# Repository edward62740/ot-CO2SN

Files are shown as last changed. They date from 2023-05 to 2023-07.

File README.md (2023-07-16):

# ot-CO2SN
 
## Overview

This is a photoacoustic NDIR CO<sub>2</sub> sensor node, utilizing energy harvesting from PV cells to allow for batteryless operation.[^1]<br>
The sensor communicates with the backend/database through 6LoWPAN on a Thread network.

Refer to the functional block diagram below for an overview of the circuit design. <br><br>
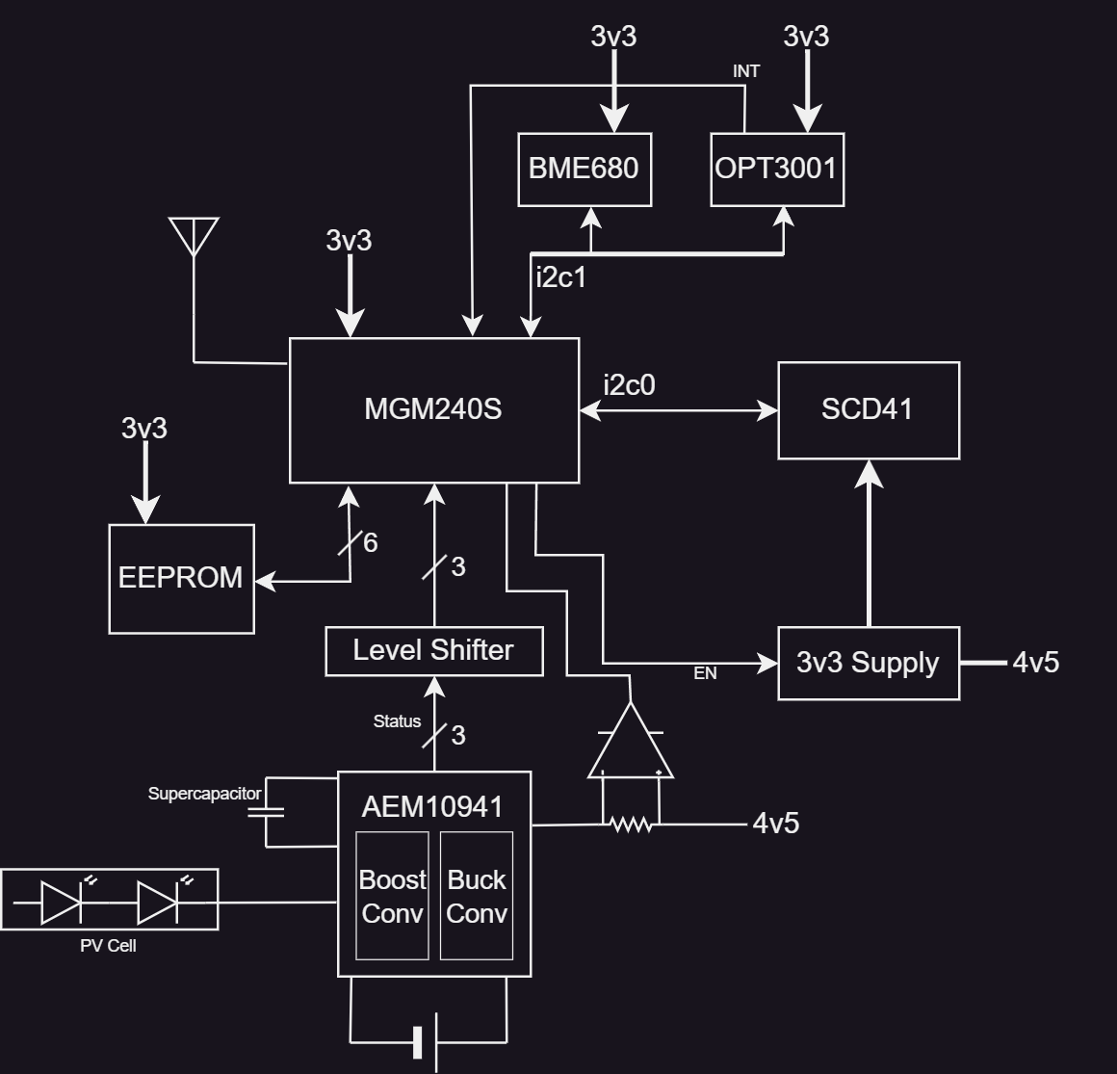
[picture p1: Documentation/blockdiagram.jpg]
Block Diagram
<br>
*Figure 1: CO2SN Functional Block Diagram*
<br><br>
The figures below depict the custom PCB and enclosure.
<br>
<div>
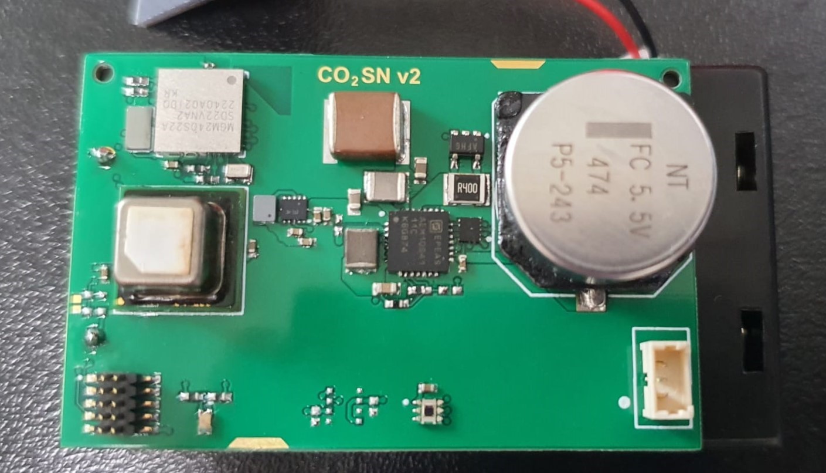
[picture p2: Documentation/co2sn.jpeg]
    
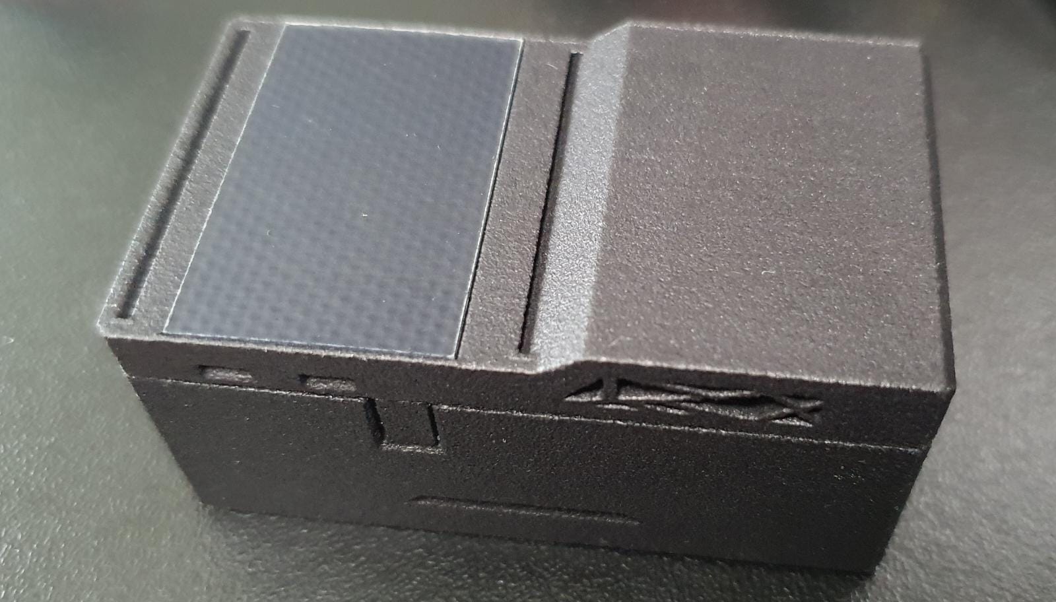
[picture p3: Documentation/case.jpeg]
    
</div>

*Figure 2a: CO2SN PCB(left), Figure 2b: CO2SN Enclosure (right)*

## Energy Harvesting and Power Management
In general, there are 3 power sources used: the PV cell array (SM141K05TF), supercapacitor (FC0H474ZF), and 2xAA (optional) backup.<br>
The primary assumption is that this sensor will receive only indirect sunlight and/or artificial lighting, hence a larger capacity from other storage technologies such as LIC/Li-ion may not be preferable if the capacity cannot be properly utilized, hence the use of a supercapacitor for the expected multiple discharges (including partial ones) per day. Furthermore, exposure to direct sunlight will introduce a non-trivial heating effect on the sensor elements; it is not known how the sensor readings would be affected. <br>
In the daytime, indoor lighting (approx. 350lux) is largely sufficient to indefinitely sustain a 1.5h sampling rate.
For completely non-battery backed operation, assuming a fully-charged supercapacitor with $1.551\text{C}$, can sustain maximally 10 cycles of CO2 measurements taking up $108\text{mC}$ each. In practice, self-discharge of the supercapacitor and quiescent currents are not negligible, and any sampling rate exceeding 1.5h should be backed up with the 2xAA for night-time operation.<br>

The sensor can also be configured to run completely off batteries.<br>
 
The quiescent power consumption (I<sub>Q</sub>) breakdown by design for all non-trivial loads at T<sub>A</sub>=25 degC are as follows:
| Device | Current Consumption (Typ) | Conditions |
|---|---|---|
| ST1PS03  | 500nA | |
| MGM240S  | 2.9µA | 256kB RAM on, LFXO  |
| AEM10941 | 0.5µA | LDO off |
| OPT3001  | 0.4µA | FS Lux |
| SCD41 | 0.5µA | PD |
| MAX9634  | 1.1µA | |

Initial designs where the sensors were segmented into seperate power domains and power gated did not yield good results, in some cases even increasing the total power due to cold start-up sequences.<br>
The supercapacitor (FC0H474ZF) maintains a charge current of <2µA after the initial absorption current. This will be assumed to be the leakage current I<sub>LEAK</sub> for all V<sub>cap</sub> > V<sub>hold</sub>. The self-discharge characteristic is given by an exponential, then a linear decay [[2]](#2).<br>

Based on empirical data (measured at the V<sub>BACK</sub> node, the average current of the system can be estimated (with the use of the [algorithm](#algorithm)):
<br><br>
$I_{\text{meas}} = \left[\frac{{50.8\text{mA} \times 1.276 \times 2 + 0.12\text{mA} \times (5-1.276) \times 2 + 0.02 \times 4.2}}{{10.02}}\right] = 12.83\text{mA}$<br>
$I_{\text{avg}} = (I_{Q} + I_{LEAK}) + \left(I_{\text{meas}} \times \frac{{10.02}}{{3600}}\right) \times \{\text{MEASUREMENTS/hr}} \text{  mA}$

For a typical application, such as in a home, CO<sub>2</sub> rates change logarithmically [[1]](#1) provided some ventilation. Hence, sample rate could be adjusted based on the previous measurements' rate of change. <br>

However, in most cases, a sample rate of 30mins-1h (<115µA) is sufficient to detect dangerous changes in indoor CO<sub>2</sub> concentrations. With approx. 350 lux from an indoor LED source in the range 400-1000nm (where the QE exceeds 80%), batteryless operation is achievable. <br>

## Algorithm
This project utilizes a custom [algorithm](https://github.com/edward62740/SCD4x-LPC) designed for ultra-low power applications such as this one, where the manufacturer supplied algorithm is unworkable.<br>

The algorithm is designed to closely mirror the built-in algorithm.

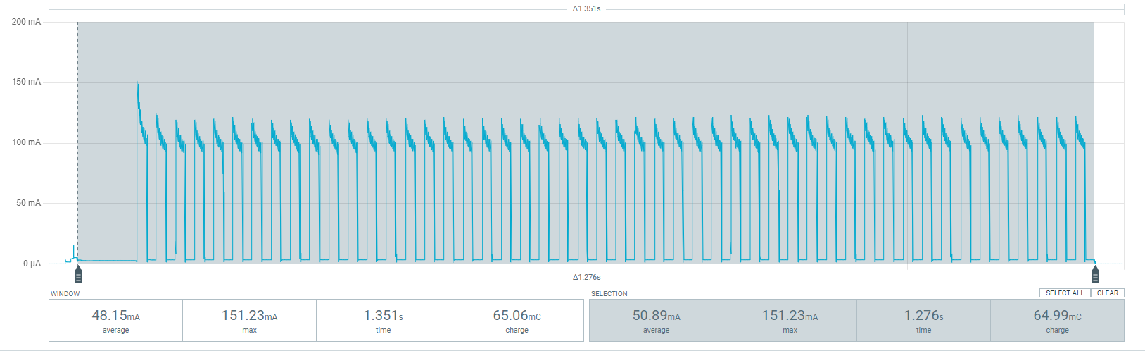
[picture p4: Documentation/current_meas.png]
<br>
*Figure 3: Current profile (SCD41 measuring)*

## Communication
Figure 4 denotes the typical communication sequence that the device performs to send measurements to the InfluxDB database.<br>
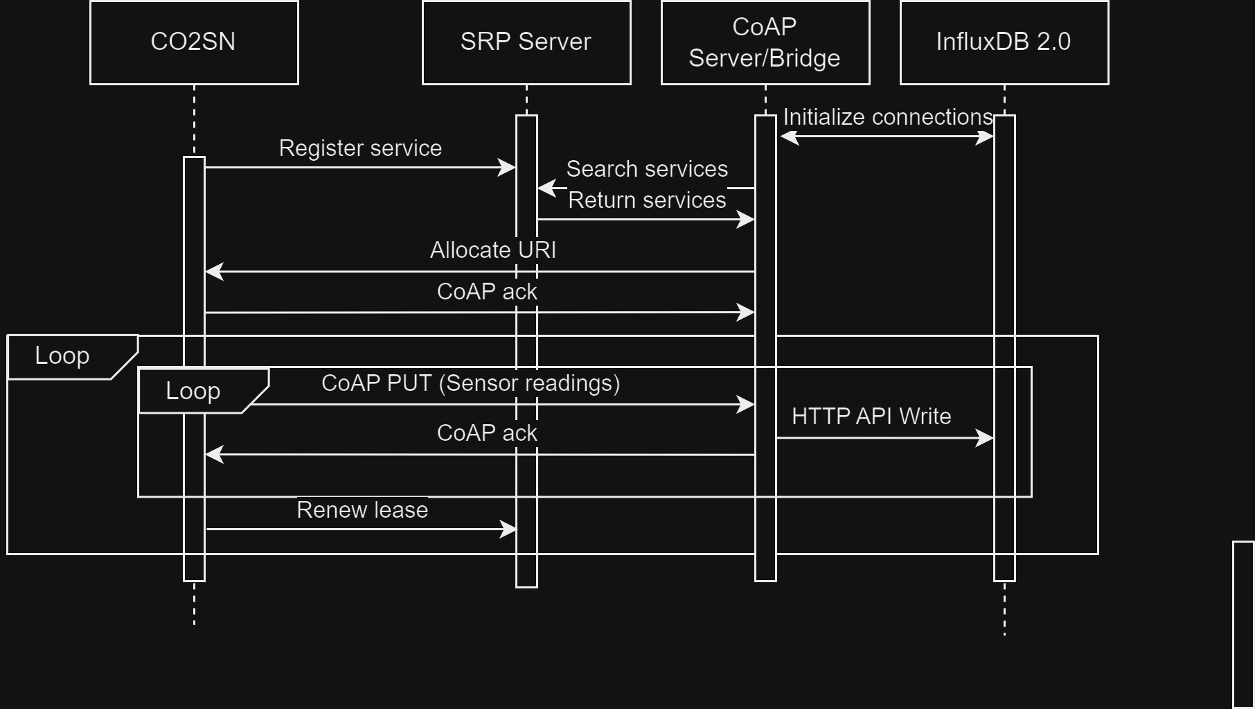
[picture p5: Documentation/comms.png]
Comms
<br>
*Figure 4: Communication Sequence Diagram*

CoAP packets containing measurement data are sent aggressively (i.e. require ACK and repeated until received), while ordinary status or informational packets are fire-and-forget, in order not to waste a measurement. 

[^1]: This sensor is optionally battery backed by 2xAA cells, to allow for higher sampling frequencies and redundancy.

## References
<a id="1">[1]</a>
Batog, P., & Badura, M. (2013). Dynamic of Changes in Carbon Dioxide Concentration in Bedrooms. Procedia Engineering, 57, 175–182. https://doi.org/10.1016/j.proeng.2013.04.025
<br>
<a id="2">[2]</a>
Kowal, J., Avaroglu, E., Chamekh, F., Šenfelds, A., Thien, T., Wijaya, D., & Sauer, D. U. (2011). Detailed analysis of the self-discharge of supercapacitors. Journal of Power Sources, 196(1), 573-579.

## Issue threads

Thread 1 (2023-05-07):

Board Bring-up Test

edward62740, 2023-05-07:
Tests to be conducted to verify appropriate performance of board.

- [x] Microcontroller
  - [x] Program/DEBUG/PTI test
  - [x] i2c0 test (scd)
  - [x] i2c1 test
  - [x] spi eeprom test
- [x] AEM subsystem
  - [x] power control
  - [x] status indicators
  - [x] source switchover
  - [x] load test @ 19dbm

- [x] ADC pri battery monitor
- [x] ADC subsys current monitor
- [ ] scd vreg control test

- [x] i2c devices functionality
- [x] power cycle scd test
- [x] RF performance characterization s11 ok, imp 53-j15

Closed 2023-07-15.

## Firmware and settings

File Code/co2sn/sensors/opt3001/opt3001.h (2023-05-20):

/*
 * opt3001.h
 *
 *  Created on: Dec 12, 2022
 *      Author: edward62740
 */

#ifndef OPT3001_H_
#define OPT3001_H_

#include <stdint.h>
#ifdef __cplusplus
extern "C" {
#endif

#define DEFAULT_CONFIG_800    0b1100110000010000 // 800ms
#define DEFAULT_CONFIG_800_OS 0b1100101000010000 // 800ms, one shot

#define DEFAULT_CONFIG_100    0b1100010000010000 // 100ms
#define DEFAULT_CONFIG_100_OS 0b1100001000010000 // 100ms, one shot

#define DEFAULT_CONFIG_SHDWN  0xc810 // Shut down converter

/*  CONFIG REGISTER BITS: RN3 RN2 RN1 RN0 CT M1 M0 OVF CRF FH FL L Pol ME FC1 FC0
    RN3 to RN0 = Range select:
                    1100 by default, enables auto-range
    CT = Conversion time bit
                    0 = 100ms conversion time
                    1 = 800ms conversion time (default)
    M1 to M0 = Mode bits
                    00 = Shutdown mode
                    01 = Single shot mode
                    10 = Continuous conversion (default)
                    11 = Continuous conversion
    OVF (Bit 8)     Overflow flag. When set the conversion result is overflown.
    CRF (Bit 7)     Conversion ready flag. Sets at end of conversion. Clears by read or write of the Configuration register.
    FH (Bit 6)      Flag high bit. Read only. Sets when result is higher that TH register. Clears when Config register is
                    read or when Latch bit is 0 and the result goes bellow TH register.
    FL (Bit 5)      Flag low bit. Read only. Sets when result is lower that TL register. Clears when Config register is read
                    or when Latch bit is 0 and the result goes above TL register.
    L (Bit 4)       Latch bit. Read/write bit. Default 1, Controls Latch/transparent functionality of FH and FL bits. When
                    L = 1 the Alert pin works in window comparator mode with Latched functionality When L = 0 the Alert pin
                    works in transparent mode and the two limit registers provide the hysteresis.
    Pol (Bit 3)     Polarity. Read/write bit. Default 0, Controls the active state of the Alert pin. Pol = 0 means Alert
                    active low.
    ME (Bit 2)      Exponent mask. In fixed range modes masks the exponent bits in the result register to 0000.
    FC1 to FC0  -   Fault count bits. Read/write bits. Default 00 - the first fault will trigger the alert pin.
*/

uint16_t opt3001_read_reg(uint8_t reg);
void opt3001_write_reg(uint8_t reg, uint8_t dataL, uint8_t dataH);
void opt3001_init();
uint16_t opt3001_read(void);
float opt3001_conv(uint16_t raw);
void opt3001_deinit(void);
int opt3001_is_measuring(void);



#define OPT3001_CFG_FL          (1 << 5)
#define OPT3001_CFG_FH          (1 << 6)
#define OPT3001_CFG_CRF         (1 << 7)
#define OPT3001_CFG_OVF         (1 << 8)
#define OPT3001_CFG_L           (1 << 4)
#define OPT3001_CFG_POL         (1 << 3)
#define OPT3001_CFG_ME          (1 << 2)
#define OPT3001_CFG_CT          (1 << 11)
#define OPT3001_CFG_FC_SHIFT    0
#define OPT3001_CFG_FC_MASK     (0x03 << OPT3001_CFG_FC_SHIFT)
#define OPT3001_CFG_M_SHIFT     9
#define OPT3001_CFG_M_MASK      (0x03 << OPT3001_CFG_M_SHIFT)
#define OPT3001_CFG_RN_SHIFT    12
#define OPT3001_CFG_RN_MASK     (0xf << OPT3001_CFG_RN_SHIFT)


#ifdef __cplusplus
}
#endif /* __cplusplus */


#endif /* OPT3001_H_ */

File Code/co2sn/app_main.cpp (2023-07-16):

#include <app_main.h>
#include <app_thread.h>
#include <app_coap.h>
#include "app_dns.h"
#include <assert.h>
#include <openthread-core-config.h>
#include <openthread/config.h>
#include <openthread/cli.h>
#include <openthread/diag.h>
#include <openthread/tasklet.h>
#include <openthread/thread.h>
#include <openthread/srp_client.h>
#include <openthread/srp_client_buffers.h>
#include "openthread-system.h"
#include "sl_ot_init.h"
#include "sl_component_catalog.h"
#include "em_burtc.h"
#include "em_iadc.h"
#include "em_gpio.h"
#include "sensors/scd4x/scd4x_i2c.h"
#include "sensors/scd4x/scd4x_lpc.h"
#include "sensors/opt3001/opt3001.h"
#include "sl_sleeptimer.h"
#include "sl_system_process_action.h"
#include <stdio.h>
#include <string.h>

static otInstance* sInstance = NULL;

constexpr static uint32_t VSENSE_DIV_MULTIPLIER = 2;
extern "C" void otAppCliInit(otInstance *aInstance);
static void appSrpInit(void);
static void app_scd_algo(void);
static void app_power_status(void);

eui_t eui; // device EUI64
app_data_t app_data = {}; // application public variables
LPC::SCD4X scd41(scd4x_wake_up, scd4x_power_down, scd4x_measure_single_shot,
		scd4x_get_data_ready_flag, scd4x_read_measurement, scd4x_perform_forced_recalibration,
		scd4x_persist_settings, sl_sleeptimer_get_tick_count); // LPC instance


constexpr static uint32_t SLEEPY_POLL_PERIOD_MS = 5 * 1000;
constexpr static uint32_t ALIVE_SLEEPTIMER_INTERVAL_MS = 60 * 1000;
constexpr static uint32_t MEASUREMENT_INTERVAL_MS = 1800 * 1000;

/* application scd41 state variables    */
/* isOn -> isDiscarded -> isMeas  */
/* ^----------------------------  */
static volatile struct
{
	bool isOn = false;
	bool isDiscarded = false;
	bool isMeas = false;
	bool LOCK = false;
	LPC::lpc_ret ret = LPC::ERR_NONE;
} scd41_state;

static bool appSrpDone = false;
static bool appCoapSendAlive = false;
sl_sleeptimer_timer_handle_t alive_timer;


dns d(otGetInstance, 4, 4);

/** HANDLERS/ISR **/
void alive_cb(sl_sleeptimer_timer_handle_t *handle, void *data)
{
	appCoapSendAlive = true;
}

void IADC_IRQHandler(void) {
	IADC_Result_t sample;
	sample = IADC_pullSingleFifoResult(IADC0);
	app_data.vdd = ((sample.data * 1200) / 1000) * VSENSE_DIV_MULTIPLIER;
	IADC_clearInt(IADC0, IADC_IF_SINGLEDONE);
}


void BURTC_IRQHandler(void)
{
    BURTC_IntClear(BURTC_IF_COMP); // compare match
	BURTC_CounterReset();
	BURTC_Stop();
	if(scd41_state.LOCK)
	{
		/* application state transition */
		if (!scd41_state.isOn)
			scd41_state.isOn = true;
		else if (!scd41_state.isDiscarded && !scd41_state.isMeas) {
			scd41_state.isDiscarded = true;
		} else if (scd41_state.isDiscarded && !scd41_state.isMeas) {
			scd41_state.isMeas = true;
		} else if (scd41_state.isDiscarded && scd41_state.isMeas) {
			scd41_state.isDiscarded = false;
			scd41_state.isMeas = false;
			scd41_state.isOn = false;
		}
		scd41_state.LOCK = false;
	}



	BURTC_IntDisable(BURTC_IEN_COMP);
}


/** Application STARTUP **/

void app_init(void)
{
    sleepyInit(SLEEPY_POLL_PERIOD_MS);
    setNetworkConfiguration();
    assert(otIp6SetEnabled(sInstance, true) == OT_ERROR_NONE);
    assert(otThreadSetEnabled(sInstance, true) == OT_ERROR_NONE);
    appCoapInit();
    appSrpInit();
    GPIO_PinOutClear(ACT_LED_PORT, ACT_LED_PIN);
	eui._64b = SYSTEM_GetUnique();
	sl_sleeptimer_start_periodic_timer_ms(&alive_timer,
			ALIVE_SLEEPTIMER_INTERVAL_MS, alive_cb, NULL, 0, 0);
}

/** Application LOOP **/

void app_process_action(void)
{
    otTaskletsProcess(sInstance);
    otSysProcessDrivers(sInstance);
    app_scd_algo();
    if(app_data.isPend) app_data.isPend = !appCoapCts(&app_data, MSG_DATA);
    else if(appCoapSendAlive) { appCoapCts(&app_data, MSG_ALIVE); appCoapSendAlive = false; }
}

/** Application SCD4x LOGIC **/

static void app_scd_algo(void) {
	if (scd41_state.LOCK)
		return;

	scd41_state.LOCK = true;

	if (!scd41_state.isOn) {
		scd41_state.ret = scd41.powerOn();
		//otCliOutputFormat("power on %d, \n", scd41_state.ret);
		BURTC_CounterReset();
		BURTC_CompareSet(0, 20);
		BURTC_IntEnable(BURTC_IEN_COMP);

	} else if (!scd41_state.isDiscarded && !scd41_state.isMeas) {
		scd41_state.ret = scd41.discardMeasurement();
		//otCliOutputFormat("discard %d, \n", scd41_state.ret);
		otIp6Address *tmp;
		uint8_t num = 0;

		if(d.resolveIpResultReady(&tmp, &num))
		{
			//otCliOutputFormat(
			//		"**Application layer resolve complete, found %d devices**\n",
			//		num);
			for (uint8_t i = 0; i < num; i++) {
				char buf[OT_IP6_ADDRESS_STRING_SIZE];

				otIp6AddressToString(&tmp[i], buf,
						sizeof(buf));
				//otCliOutputFormat("%s\n ", buf);

			}
		}
		//if(!d.browseResultIsOverflow()) otCliOutputFormat("Assert: Success \n\n");
		//else  otCliOutputFormat("Assert: More entries than buffers \n\n");
		BURTC_CounterReset();
		BURTC_CompareSet(0, 5200);
		BURTC_IntEnable(BURTC_IEN_COMP);

	} else if (scd41_state.isDiscarded && !scd41_state.isMeas) {
		scd41_state.ret = scd41.measure();
		//otCliOutputFormat("meas %d, \n", scd41_state.ret);
		BURTC_CounterReset();
		BURTC_CompareSet(0, 5200);
		BURTC_IntEnable(BURTC_IEN_COMP);

	} else if (scd41_state.isDiscarded && scd41_state.isMeas) {
		GPIO_PinOutSet(ERR_LED_PORT, ERR_LED_PIN);
		scd41_state.ret = scd41.read(&app_data.co2, &app_data.temp, &app_data.hum);
		//otCliOutputFormat(
				//"Measurement result: CO2 %d, temp %d, hum %d  ERR code: %d \r\n",
				//app_data.co2, app_data.temp, app_data.hum, scd41_state.ret);
		//GPIO_PinOutSet(PWR_EN_ST_PORT, PWR_EN_ST_PIN);
		scd41.get_last_frc(&app_data.offset, &app_data.age, &app_data.num);
		//otCliOutputFormat(
			//	"calibration result: Cycles ago: %d, Offset: %d, Total: %d \r\n",
				//app_data.age, app_data.offset, app_data.num);
		app_power_status();
		//GPIO_PinOutClear(PWR_EN_ST_PORT, PWR_EN_ST_PIN);
		scd41_state.ret = scd41.powerOff();
		app_data.isPend = !appCoapCts(&app_data, MSG_DATA);
		//d.browse("_ot._udp.default.service.arpa.");
		//d.resolveHost("server", "_ing._udp.default.service.arpa.");
		//d.resolve4("google.com");
		BURTC_CounterReset();
		BURTC_CompareSet(0, MEASUREMENT_INTERVAL_MS);
		BURTC_IntEnable(BURTC_IEN_COMP);
		GPIO_PinOutClear(ERR_LED_PORT, ERR_LED_PIN);
	}
}



static void appSrpInit(void)
{
    if(appSrpDone) return;
    appSrpDone = true;

    otError error = OT_ERROR_NONE;

    char *hostName;
    const char *HOST_NAME = "OT-CO2SN-0";
    uint16_t size;
    hostName = otSrpClientBuffersGetHostNameString(sInstance, &size);
    error = otSrpClientSetHostName(sInstance, HOST_NAME);
    memcpy(hostName, HOST_NAME, sizeof(HOST_NAME) + 1);

    otSrpClientEnableAutoHostAddress(sInstance);


    otSrpClientBuffersServiceEntry *entry = NULL;
    char *string;

    entry = otSrpClientBuffersAllocateService(sInstance);

    entry->mService.mPort = 33434;
    char INST_NAME[32];
    snprintf(INST_NAME, 32, "ipv6bc%d", (uint8_t)(eui._64b & 0xFF));
    const char *SERV_NAME = "_ot._udp";
    string = otSrpClientBuffersGetServiceEntryInstanceNameString(entry, &size);
    memcpy(string, INST_NAME, size);


    string = otSrpClientBuffersGetServiceEntryServiceNameString(entry, &size);
    memcpy(string, SERV_NAME, size);

    error = otSrpClientAddService(sInstance, &entry->mService);

    assert(OT_ERROR_NONE == error);

    entry = NULL;

    otSrpClientEnableAutoStartMode(sInstance, /* aCallback */ NULL, /* aContext */ NULL);
}




static void app_power_status(void)
{
	app_data.pwr_state = (GPIO_PinInGet(PWR_ST_0_PORT, PWR_ST_0_PIN) & 0x1) |
			(GPIO_PinInGet(PWR_ST_1_PORT, PWR_ST_1_PIN) & 0x1) << 1;
}


/*
 * Provide, if required an "otPlatLog()" function
 */
#if OPENTHREAD_CONFIG_LOG_OUTPUT == OPENTHREAD_CONFIG_LOG_OUTPUT_APP
void otPlatLog(otLogLevel aLogLevel, otLogRegion aLogRegion, const char *aFormat, ...)
{
    OT_UNUSED_VARIABLE(aLogLevel);
    OT_UNUSED_VARIABLE(aLogRegion);
    OT_UNUSED_VARIABLE(aFormat);

    va_list ap;
    va_start(ap, aFormat);
    otCliPlatLogv(aLogLevel, aLogRegion, aFormat, ap);
    va_end(ap);
}
#endif

void sl_ot_create_instance(void)
{
#if OPENTHREAD_CONFIG_MULTIPLE_INSTANCE_ENABLE
    size_t   otInstanceBufferLength = 0;
    uint8_t *otInstanceBuffer       = NULL;

    // Call to query the buffer size
    (void)otInstanceInit(NULL, &otInstanceBufferLength);

    // Call to allocate the buffer
    otInstanceBuffer = (uint8_t *)malloc(otInstanceBufferLength);
    assert(otInstanceBuffer);

    // Initialize OpenThread with the buffer
    sInstance = otInstanceInit(otInstanceBuffer, &otInstanceBufferLength);
#else
    sInstance = otInstanceInitSingle();
#endif
    assert(sInstance);
}

void sl_ot_cli_init(void)
{
    //otAppCliInit(sInstance);
}


otInstance *otGetInstance(void)
{
    return sInstance;
}


/**************************************************************************//**
 * Application Exit.`
 *****************************************************************************/
void app_exit(void)
{
    otInstanceFinalize(sInstance);
}

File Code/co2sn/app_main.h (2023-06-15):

#ifndef APP_H
#define APP_H

#include "sensors/scd4x/scd4x_i2c.h"
#include "sensors/scd4x/scd4x_lpc.h"
#include <openthread/instance.h>
#include "sl_sleeptimer.h"

#ifdef __cplusplus
extern "C" {
#endif

extern LPC::SCD4X scd41;

typedef union {
    uint64_t _64b;
    struct {
        uint32_t l;
        uint32_t h;
    } _32b;
} eui_t;


typedef struct
{
	bool isPend;
	bool error;
	uint16_t co2;
	int32_t hum, temp;

	int32_t offset;
	uint32_t age, num;

	volatile uint32_t vdd;
	uint8_t pwr_state;
} app_data_t;


extern eui_t eui;
extern app_data_t app_data;

extern sl_sleeptimer_timer_handle_t alive_timer;
void alive_cb(sl_sleeptimer_timer_handle_t *handle, void *data);

void app_init(void);

void app_exit(void);

void app_process_action(void);

otInstance *otGetInstance(void);

#define ACT_LED_PORT     gpioPortB
#define ACT_LED_PIN      2
#define ERR_LED_PORT     gpioPortB
#define ERR_LED_PIN      3


#define INT_OPT_PORT     gpioPortD
#define INT_OPT_PIN      5



#define PWR_ST_0_PORT    gpioPortC
#define PWR_ST_0_PIN     0
#define PWR_ST_1_PORT    gpioPortC
#define PWR_ST_1_PIN     1
#define PWR_ST_2_PORT    gpioPortC
#define PWR_ST_2_PIN     2
#define PWR_EN_ST_PORT   gpioPortC
#define PWR_EN_ST_PIN    3

#define PWR_PG_MCU_PORT  gpioPortC
#define PWR_PG_MCU_PIN   4
#define PWR_PG_SCD_PORT  gpioPortC
#define PWR_PG_SCD_PIN   5
#define PWR_EN_SCD_PORT  gpioPortC
#define PWR_EN_SCD_PIN   6

#define LOAD_SENSE_PORT  gpioPortC
#define LOAD_SENSE_PIN   7


void setNetworkConfiguration(void);
void initUdp(void);
void applicationTick(void);
void sl_ot_create_instance(void);
void sl_ot_cli_init(void);

#ifdef __cplusplus
}
#endif /* __cplusplus */


#endif

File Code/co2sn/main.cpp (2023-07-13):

/*
 *  main.c
 *
 *  Created on: May 20, 2023
 *      Author: edward62740
 */

#include <app_main.h>
#include "sl_component_catalog.h"
#include "sl_system_init.h"
#include "em_i2c.h"
#include "em_cmu.h"
#include "em_burtc.h"
#include "em_prs.h"
#include "em_iadc.h"
#include "sl_i2cspm.h"
#include "sl_sleeptimer.h"

#include "sensors/scd4x/scd4x_i2c.h"
#include "sensors/scd4x/scd4x_lpc.h"
#include "sensors/opt3001/opt3001.h"
#if defined(SL_CATALOG_POWER_MANAGER_PRESENT)
#include "sl_power_manager.h"
#endif // SL_CATALOG_POWER_MANAGER_PRESENT
#if defined(SL_CATALOG_KERNEL_PRESENT)
#include "sl_system_kernel.h"
#else // !SL_CATALOG_KERNEL_PRESENT
#include "sl_system_process_action.h"
#endif // SL_CATALOG_KERNEL_PRESENT

#include <openthread/cli.h>
#include <openthread/platform/logging.h>


I2C_TransferReturn_TypeDef I2C_detect1(I2C_TypeDef *i2c, uint8_t addr) {

	I2C_TransferSeq_TypeDef i2cTransfer;
	I2C_TransferReturn_TypeDef result;

	// Initialize I2C transfer
	i2cTransfer.addr = addr << 1;
	i2cTransfer.flags = I2C_FLAG_WRITE;
	i2cTransfer.buf[0].data = NULL;
	i2cTransfer.buf[0].len = 0;

	return I2CSPM_Transfer(i2c, &i2cTransfer);

}

void initGPIO(void) {
	CMU_ClockEnable(cmuClock_GPIO, true);
	GPIO_PinModeSet(PWR_ST_0_PORT, PWR_ST_0_PIN, gpioModeInput, 1); // Asserted when the LDOs can be enabled (i.e. Vbatt > Vchrdy)
	GPIO_PinModeSet(PWR_ST_1_PORT, PWR_ST_1_PIN, gpioModeInput, 1); // Asserted if the battery voltage falls below Vovdis or if the AEM is taking energy from the primary battery
	GPIO_PinModeSet(PWR_ST_2_PORT, PWR_ST_2_PIN, gpioModeInput, 1); // Asserted when the AEM performs a MPP evaluation

	GPIO_PinModeSet(PWR_EN_ST_PORT, PWR_EN_ST_PIN, gpioModeInput, 1); // Enable status pins
	GPIO_PinModeSet(PWR_EN_SCD_PORT, PWR_EN_SCD_PIN, gpioModeInput, 1); // Enable SCD power

	GPIO_PinModeSet(PWR_PG_MCU_PORT, PWR_PG_MCU_PIN, gpioModeInput, 1); // MCU power good
	GPIO_PinModeSet(PWR_PG_SCD_PORT, PWR_PG_SCD_PIN, gpioModeInput, 1); // SCD power good

	GPIO_PinModeSet(LOAD_SENSE_PORT, LOAD_SENSE_PIN, gpioModeInputPull, 0); // TBD single ended analog signal

	/*GPIO_ExtIntConfig(A111_INT_PORT,
	 A111_INT_PIN,
	 A111_INT_PIN,
	 true,
	 false,
	 true);*/

	GPIO_PinModeSet(INT_OPT_PORT, INT_OPT_PIN, gpioModeInputPullFilter, 0); // OPT interrupt
	GPIO_PinModeSet(ACT_LED_PORT, ACT_LED_PIN, gpioModePushPull, 0);
	GPIO_PinModeSet(ERR_LED_PORT, ERR_LED_PIN, gpioModePushPull, 0);

	//GPIO_PinOutSet(PWR_EN_SCD_PORT, PWR_EN_SCD_PIN);
}

void initBURTC(void) {
	CMU_ClockSelectSet(cmuClock_EM4GRPACLK, cmuSelect_ULFRCO);
	CMU_ClockEnable(cmuClock_BURTC, true);
	CMU_ClockEnable(cmuClock_BURAM, true);

	BURTC_Init_TypeDef burtcInit = BURTC_INIT_DEFAULT;
	burtcInit.compare0Top = true; // reset counter when counter reaches compare value
	burtcInit.em4comp = true; // BURTC compare interrupt wakes from EM4 (causes reset)
	BURTC_Init(&burtcInit);
	BURTC_IntEnable(BURTC_IEN_COMP);      // compare match
	NVIC_EnableIRQ(BURTC_IRQn);
	BURTC_Enable(true);
}

void initSensors(void) {
	opt3001_init();
}

void initVddMonitor(void) {
	IADC_Init_t init = IADC_INIT_DEFAULT;
	IADC_AllConfigs_t initAllConfigs = IADC_ALLCONFIGS_DEFAULT;
	IADC_InitSingle_t initSingle = IADC_INITSINGLE_DEFAULT;
	IADC_SingleInput_t singleInput = IADC_SINGLEINPUT_DEFAULT;

	CMU_ClockEnable(cmuClock_PRS, true);
	PRS_SourceAsyncSignalSet(0,
	PRS_ASYNC_CH_CTRL_SOURCESEL_MODEM,
	PRS_MODEMH_PRESENT);
	PRS_ConnectConsumer(0, prsTypeAsync, prsConsumerIADC0_SINGLETRIGGER);
	CMU_ClockEnable(cmuClock_IADC0, true);
	initAllConfigs.configs[0].reference = iadcCfgReferenceInt1V2;
	initAllConfigs.configs[0].vRef = 1200;
	initAllConfigs.configs[0].osrHighSpeed = iadcCfgOsrHighSpeed2x;

	initAllConfigs.configs[0].adcClkPrescale = IADC_calcAdcClkPrescale(
	IADC0, 1000000, 0, iadcCfgModeNormal, init.srcClkPrescale);
	initSingle.triggerSelect = iadcTriggerSelPrs0PosEdge;
	initSingle.dataValidLevel = iadcFifoCfgDvl4;
	initSingle.start = true;
	singleInput.posInput = iadcPosInputPortDPin2;
	singleInput.negInput = iadcNegInputGnd;
	IADC_init(IADC0, &init, &initAllConfigs);
	IADC_initSingle(IADC0, &initSingle, &singleInput);
	IADC_clearInt(IADC0, _IADC_IF_MASK);
	IADC_enableInt(IADC0, IADC_IEN_SINGLEDONE);
	NVIC_ClearPendingIRQ(IADC_IRQn);
	NVIC_SetPriority(GPIO_ODD_IRQn, 7);
	NVIC_EnableIRQ(IADC_IRQn);
}

int main(void) {
	sl_system_init();
	initGPIO();
	initBURTC();
	initVddMonitor();
	initSensors();
	GPIO_PinOutSet(ERR_LED_PORT, ERR_LED_PIN);
	GPIO_PinOutSet(ACT_LED_PORT, ACT_LED_PIN);
	GPIO_PinOutSet(PWR_EN_ST_PORT, PWR_EN_ST_PIN);


	float opt_buf = opt3001_conv(opt3001_read());

	GPIO_PinOutToggle(ACT_LED_PORT, ACT_LED_PIN);
	// Clean up potential SCD40 states

	scd4x_wake_up();
	sl_sleeptimer_delay_millisecond(30);
	GPIO_PinOutToggle(ACT_LED_PORT, ACT_LED_PIN);
	scd4x_set_automatic_self_calibration(0);
	sl_sleeptimer_delay_millisecond(30);
	GPIO_PinOutToggle(ACT_LED_PORT, ACT_LED_PIN);
	scd4x_stop_periodic_measurement();
	sl_sleeptimer_delay_millisecond(30);
	scd4x_power_down();

	app_init();
	GPIO_PinOutClear(ERR_LED_PORT, ERR_LED_PIN);


#if defined(SL_CATALOG_KERNEL_PRESENT)
  // Start the kernel. Task(s) created in app_init() will start running.
  sl_system_kernel_start();
#else // SL_CATALOG_KERNEL_PRESENT
	while (1) {
		// Do not remove this call: Silicon Labs components process action routine
		// must be called from the super loop.
		sl_system_process_action();

		app_process_action();

		// GPIO_PinOutToggle(ACT_LED_PORT, ACT_LED_PIN);
#if defined(SL_CATALOG_POWER_MANAGER_PRESENT)
		// Let the CPU go to sleep if the system allows it.
		sl_power_manager_sleep();
#endif
	}
	// Clean-up when exiting the application.
	app_exit();
#endif // SL_CATALOG_KERNEL_PRESENT
}

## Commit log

2023-05-07 Layout improvements and features
    - Removed gnd stubs
    - Added pri batt adc divider to mcu pd
    - Added sensor name mask clearance
    - Improved stitching around board edge
    [harvester.SchDoc, mcu.SchDoc, ot-CO2.PrjPcb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]
2023-05-20 HW test update
    [mcu.SchDoc]
2023-06-03 Improved application logic and added coap payload
    [harvester.SchDoc, mcu.SchDoc, ot-CO2.PrjPcb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]
2023-07-13 Pre-release (v1.0)
    [harvester.SchDoc, mcu.SchDoc, sensors.SchDoc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]
